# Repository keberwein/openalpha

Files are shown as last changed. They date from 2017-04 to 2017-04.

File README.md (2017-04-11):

# openalpha
Open Alpha CAD files

# Open Sourced 3D headpohne cups from MrSpeakers
These files were originally posted at www.head-fi.com with the following statement from the original authors.
As a thank you to the Head-Fi community, we're pleased to share a modified version of the Alpha Dog 3D printed headphone for the community to build DIY projects and perhaps improve on the tuning and performance of the headphone.  We are posting this fully unlicensed, though we hope people will use this for personal, not commercial purposes.

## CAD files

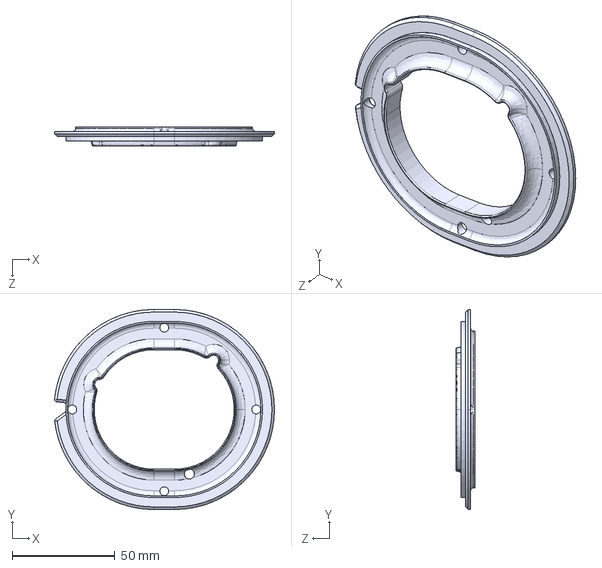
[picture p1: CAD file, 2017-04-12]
IGES/ALPHA, PAD RING.IGS
107.0 x 97.3 x 9.14 mm

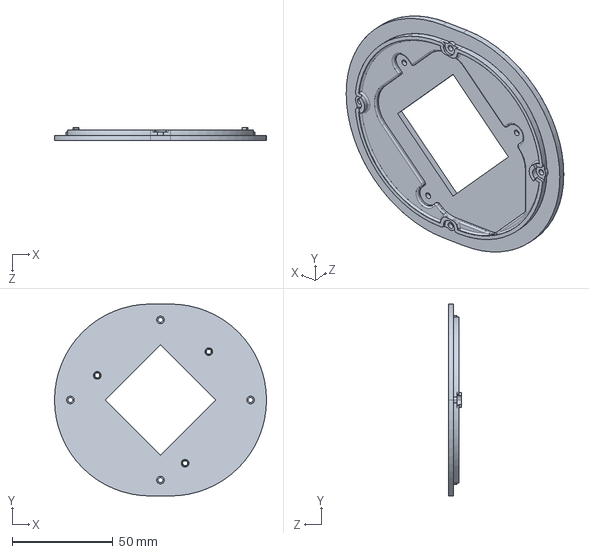
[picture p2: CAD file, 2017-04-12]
IGES/ALPHA, BAFFLE.IGS
105.2 x 95.3 x 6.35 mm

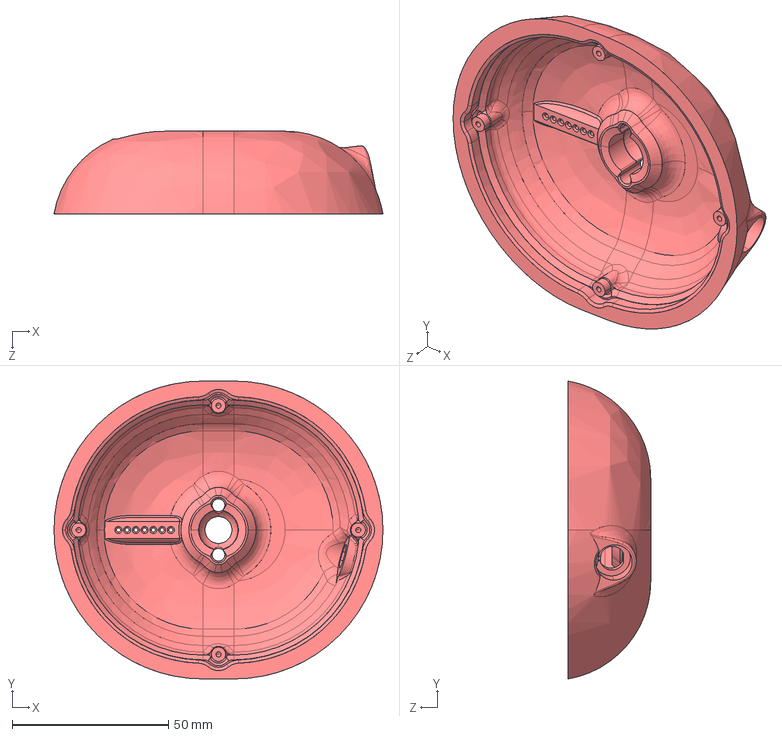
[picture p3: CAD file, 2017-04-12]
IGES/OPEN ALPHA, RIGHT CUP.IGS
105.2 x 95.3 x 26.4 mm

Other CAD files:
IGES/OPEN ALPHA, LEFT CUP.IGS
ALPHA, BAFFLE.STL
PARASOLID/ALPHA, BAFFLE.x_b
PARASOLID/ALPHA, PAD RING.x_b
PARASOLID/OPEN ALPHA, LEFT CUP.x_b
PARASOLID/OPEN ALPHA, RIGHT CUP.x_b

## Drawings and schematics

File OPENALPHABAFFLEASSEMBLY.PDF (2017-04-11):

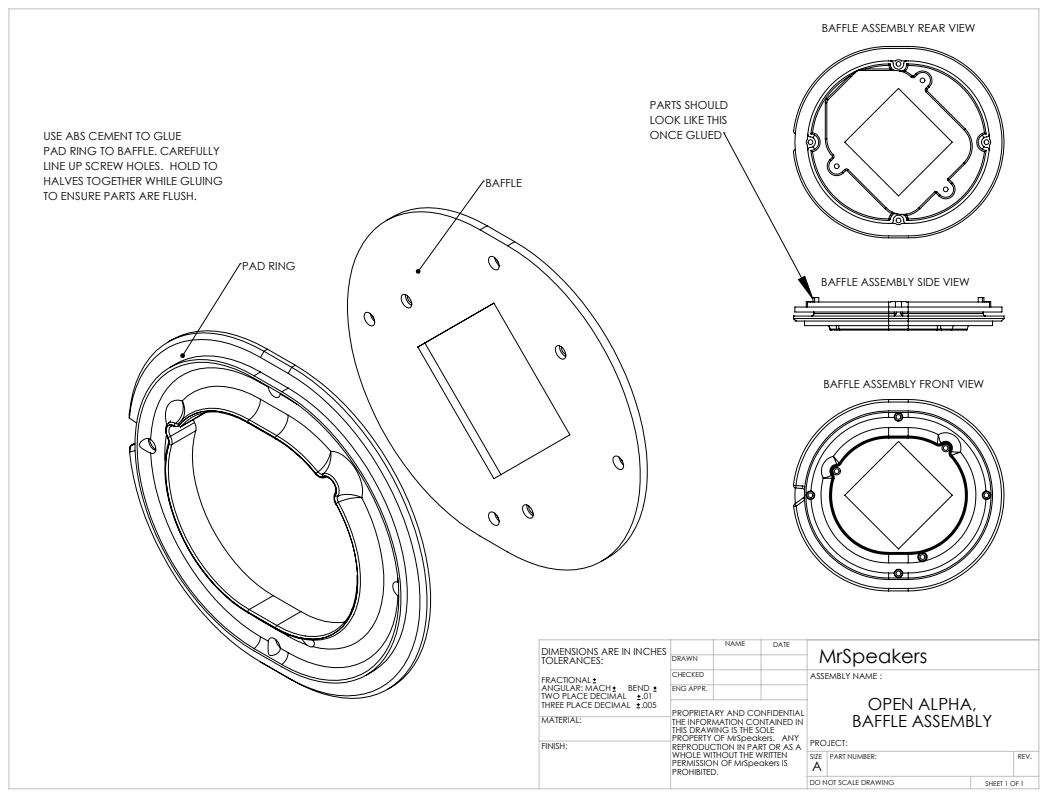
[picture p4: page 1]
PAD RING

BAFFLE ASSEMBLY REAR VIEW

PARTS SHOULD
LOOK LIKE THIS
ONCE GLUED

USE ABS CEMENT TO GLUE
PAD RING TO BAFFLE. CAREFULLY
LINE UP SCREW HOLES. HOLD TO
HALVES TOGETHER WHILE GLUING
TO ENSURE PARTS ARE FLUSH.

BAFFLE ASSEMBLY SIDE VIEW

BAFFLE ASSEMBLY FRONT VIEW

DIMENSIONS ARE IN INCHES TOLERANCES: FRACTIONAL ANGULAR: MACH BEND TWO PLACE DECIMAL .01 THREE PLACE DECIMAL .005 | | NAME | DATE | MrSpeakers

DRAWN
CHECKED | | | ASSEMBLY NAME : OPEN ALPHA, BAFFLE ASSEMBLY PROJECT:
ENG APPR.

PROPRIETARY AND CONFIDENTIAL
THE INFORMATION CONTAINED IN
THIS DRAWING IS THE SOLE
PROPERTY OF MrSpeakers. ANY
REPRODUCTION IN PART OR AS A
WHOLE WITHOUT THE WRITTEN
PERMISSION OF MrSpeakers IS
PROHIBITED.

SIZE A | PART NUMBER: | REV.

DO NOT SCALE DRAWING | SHEET 1 OF 1

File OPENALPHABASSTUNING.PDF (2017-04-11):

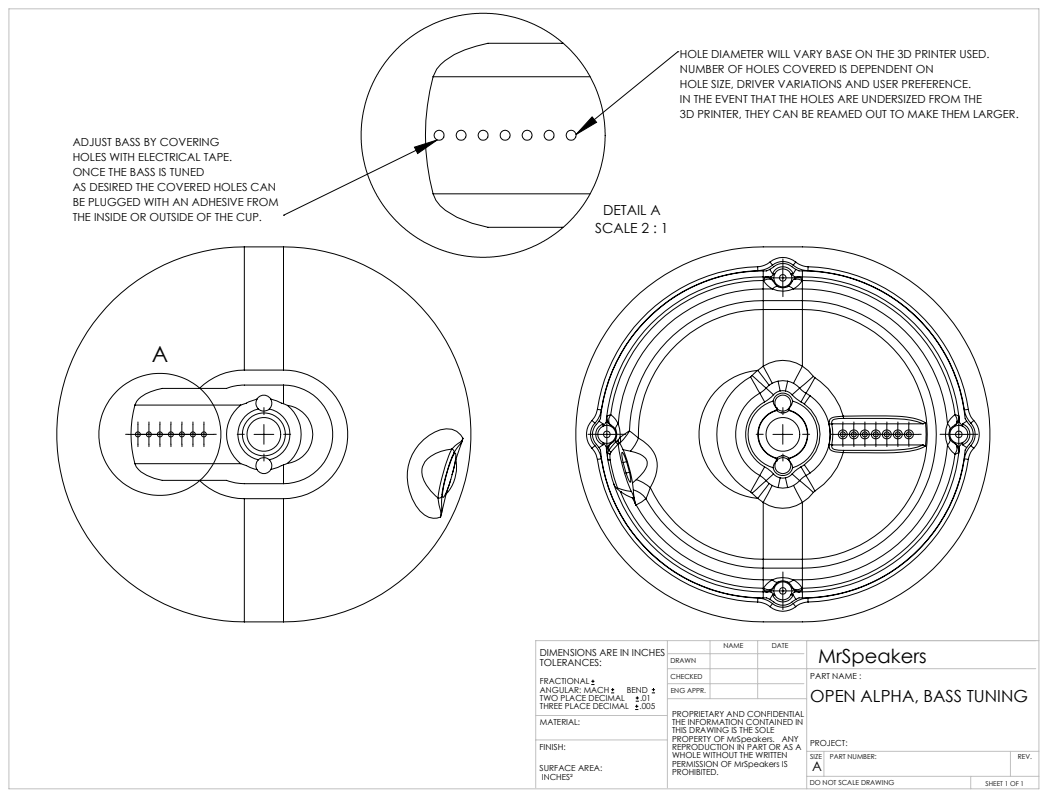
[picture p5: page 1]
DETAIL A SCALE 2 : 1

HOLE DIAMETER WILL VARY BASE ON THE 3D PRINTER USED.
NUMBER OF HOLES COVERED IS DEPENDENT ON
HOLE SIZE, DRIVER VARIATIONS AND USER PREFERENCE.
IN THE EVENT THAT THE HOLES ARE UNDERSIZED FROM THE
3D PRINTER, THEY CAN BE REAMED OUT TO MAKE THEM LARGER.

ADJUST BASS BY COVERING
HOLES WITH ELECTRICAL TAPE.
ONCE THE BASS IS TUNED
AS DESIRED THE COVERED HOLES CAN
BE PLUGGED WITH AN ADHESIVE FROM
THE INSIDE OR OUTSIDE OF THE CUP.

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

DRAWN
CHECKED | | | PART NAME : OPEN ALPHA, BASS TUNING PROJECT:
ENG APPR.

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

FINISH:
PROHIBITED. SURFACE AREA:
INCHES²

SIZE A | PART NUMBER: | REV.

DO NOT SCALE DRAWING | SHEET 1 OF 1

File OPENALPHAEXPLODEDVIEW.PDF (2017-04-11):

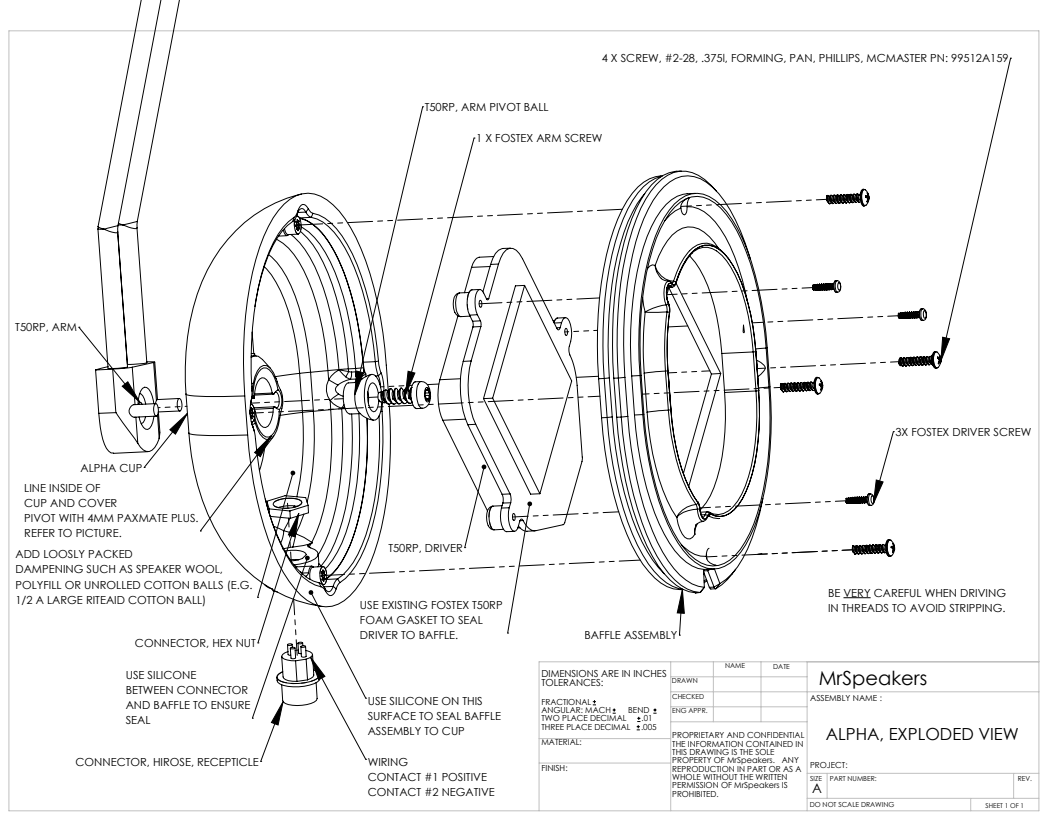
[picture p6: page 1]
T50RP, DRIVER; ALPHA CUP; T50RP, ARM; BAFFLE ASSEMBLY; CONTACT #1 POSITIVE CONTACT #2 NEGATIVE

4 X SCREW, #2-28, .375l, FORMING, PAN, PHILLIPS, MCMASTER PN: 99512A159

T50RP, ARM PIVOT BALL

1 X FOSTEX ARM SCREW

3X FOSTEX DRIVER SCREW

LINE INSIDE OF
CUP AND COVER
PIVOT WITH 4MM PAXMATE PLUS.
REFER TO PICTURE.
ADD LOOSLY PACKED
DAMPENING SUCH AS SPEAKER WOOL,
POLYFILL OR UNROLLED COTTON BALLS (E.G.
1/2 A LARGE RITEAID COTTON BALL)

BE VERY CAREFUL WHEN DRIVING
IN THREADS TO AVOID STRIPPING.

USE EXISTING FOSTEX T50RP
FOAM GASKET TO SEAL
DRIVER TO BAFFLE.

CONNECTOR, HEX NUT

USE SILICONE
BETWEEN CONNECTOR
AND BAFFLE TO ENSURE
SEAL

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

DRAWN
CHECKED | | | ASSEMBLY NAME : ALPHA, EXPLODED VIEW PROJECT:
ENG APPR.

USE SILICONE ON THIS
SURFACE TO SEAL BAFFLE
ASSEMBLY TO CUP

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

CONNECTOR, HIROSE, RECEPTICLE

SIZE A | PART NUMBER: | REV.

DO NOT SCALE DRAWING | SHEET 1 OF 1
